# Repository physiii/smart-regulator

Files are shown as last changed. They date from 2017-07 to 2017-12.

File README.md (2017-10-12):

## This repository contains the code, schematic, and layout for a wifi controlled and monitored 5V 3A regulator that works with __open-automation__.

### open-automation is made from a cohesive set of web languages. NodeJS for general processing, socket.io for bidirectional communication. NodeJS is used for generating, setting, and retreiving model (mongodb) data. Websockets is used for transport on microcontrollers. Live token based streaming with JSMPEG decoding on camera devices. Web interface is angularjs. Android app for location beacons. Now supports streaming from behind routers, this is done through websockets; so no port forwarding necessary!

### Can be used for controlling cameras, dead bolts, garage openers, lights, thermostats, media, glass break, and a customizable alert system.

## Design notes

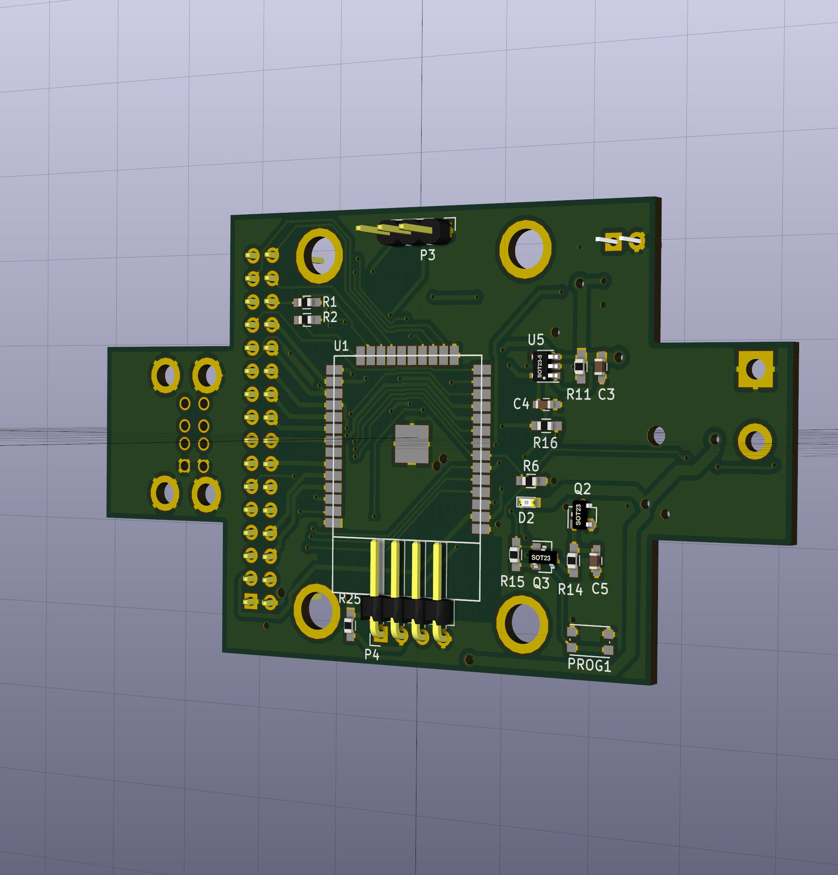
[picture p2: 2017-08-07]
images/5v-smart-solar-regulator-bottom.jpg

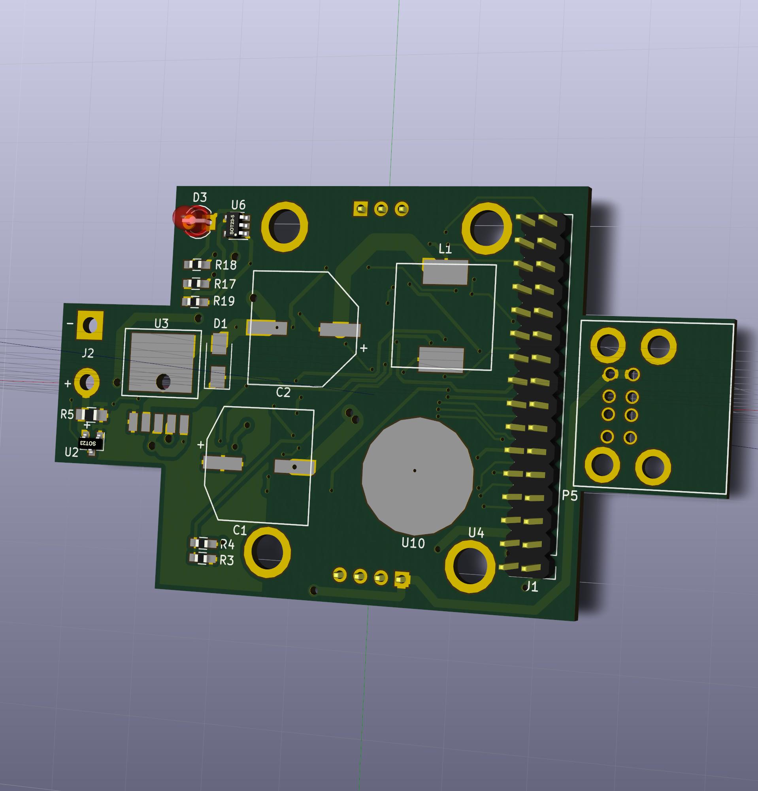
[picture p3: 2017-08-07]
images/5v-smart-solar-regulator-top.jpg

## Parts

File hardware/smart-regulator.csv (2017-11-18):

Reference | Quantity | Value | Footprint | Datasheet | Part Number
BATTERY1 PANEL1 | 2 | CONN_01X02 | open-automation:XT60 | https://www.digikey.com/product-detail/en/phoenix-contact/1934861/277-1607-ND/568644
C1 | 1 | 100uF | Capacitors_THT:CP_Radial_D10.0mm_P3.50mm | https://www.digikey.com/product-detail/en/nichicon/UVR1H101MPD/493-1107-ND/588848 | UVR1H101MPD
C2 | 1 | 1000uF | Capacitors_THT:CP_Radial_D10.0mm_P3.50mm | https://www.digikey.com/product-detail/en/nichicon/UVR0J102MPD1TD/493-12738-1-ND/4328447 | UVR0J102MPD1TD
C3 | 1 | 4.7uF | Capacitors_SMD:C_0603_HandSoldering | https://www.digikey.com/product-detail/en/samsung-electro-mechanics-america-inc/CL10B475KQ8NQNC/1276-2087-1-ND/3890173 | CL10B475KQ8NQNC
C4 | 1 | C_10uF | Capacitors_SMD:C_0603_HandSoldering | https://www.digikey.com/product-detail/en/murata-electronics-north-america/GRM188R61A106ME69D/490-10475-1-ND/5026393 | GRM188R61A106ME69D
C6 | 1 | C_1uF | Capacitors_SMD:C_0603_HandSoldering | https://www.digikey.com/product-detail/en/yageo/CC0603ZRY5V7BB105/311-1372-1-ND/2103156 | CC0603ZRY5V7BB105
C8 C9 C10 | 3 | C_0.1uF | Capacitors_SMD:C_0603_HandSoldering | https://www.digikey.com/product-detail/en/kemet/C0603C104K5RACTU/399-5089-1-ND/1465623 | C0603C104K5RACTU
D1 | 1 | D_Schottky | Diodes_SMD:D_SMA | http://www.digikey.com/scripts/DkSearch/dksus.dll?Detail&itemSeq=233263850&uq=636356340886764109 | B330A-13-F
D2 D3 D4 D5 | 4 | LED | LEDs:LED_0603_HandSoldering | http://www.osram-os.com/Graphics/XPic9/00128792_0.pdf | 475-2512-2-ND
FACTORY1 REBOOT1 PROG1 | 3 | SW_PUSH | Buttons_Switches_SMD:SW_SPST_KMR2 | http://www.mouser.com/ds/2/60/KMR2_9aug12-25127.pdf | KMR211NG LFS
J1 | 1 | Conn_02x05_Odd_Even | Pin_Headers:Pin_Header_Straight_2x05_Pitch2.54mm
L1 | 1 | 47uH | open-automation:L-RAD-7.4mm | https://www.digikey.com/product-detail/en/abracon-llc/AIUR-06-470K/535-13031-ND/2343602 | AIUR-06-470K
P5 | 1 | USB_A_2 | open-automation:USB_A_2 | https://www.digikey.com/product-detail/en/cnc-tech/1002-004-01010/1175-1018-ND/3064749 | 1002-004-01010
Q1 | 1 | Q_NMOS_GSD_AOD4184A | TO_SOT_Packages_SMD:TO-252-2_Rectifier | https://www.digikey.com/products/en?keywords=785-1221-1-ND | AOD4184A
R1 | 1 | R_10m | Resistors_SMD:R_2512_HandSoldering | https://www.digikey.com/product-detail/en/bourns-inc/CRA2512-FZ-R010ELF/CRA2512-FZ-R010ELFCT-ND/1775054 | CRA2512-FZ-R010ELF
R2 R3 R4 R6 R8 R9 R10 R11 | 8 | R_10k | Resistors_SMD:R_0603_HandSoldering | https://www.digikey.com/product-detail/en/yageo/RC0603JR-0710KL/311-10KGRCT-ND/729647 | RC0603JR-0710KL
R7 | 1 | 1K | Resistors_SMD:R_0603_HandSoldering | https://www.digikey.com/product-detail/en/yageo/RC0603JR-071KL/311-1.0KGRTR-ND/726677 | RC0603JR-071KL
U1 | 1 | ESP-WROOM-32 | open-automation:ESP-WROOM-32 | https://www.espressif.com/sites/default/files/documentation/esp_wroom_32_datasheet_en.pdf
U10 | 1 | touchpad | open-automation:touch-pad
U11 | 1 | NCP1117LPST33T3G | TO_SOT_Packages_SMD:SOT-223 | https://www.digikey.com/product-detail/en/on-semiconductor/NCP1117LPST33T3G/NCP1117LPST33T3GOSCT-ND/3462387 | NCP1117LPST33T3G
U2 | 1 | TSL45315CL | open-automation:LIGHT-SENSOR-TSL45315CL | https://www.digikey.com/product-detail/en/ams/TSL45315CL/TSL45315-CLCT-ND/3095326 | TSL45315CL
U3 | 1 | LM2576 | open-automation:Regulator-LM2576 | https://www.digikey.com/product-detail/en/texas-instruments/LM2576SX-5.0-NOPB/LM2576SX-5.0-NOPBCT-ND/3440106 | LM2576SX-5.0/NOPB
U4 | 1 | housing-mounts | open-automation:enclosure-25x38 | https://www.mcmaster.com/#catalog/123/904/=18nyvt2
U5 | 1 | Power-Monitor-INA219 | TO_SOT_Packages_SMD:SOT-23-8_Handsoldering | https://www.digikey.com/product-detail/en/texas-instruments/INA219AIDCNR/296-23770-1-ND/1952550 | INA219AIDCNR
U6 | 1 | SI7020-A20 | open-automation:SI7020-A20 | https://www.digikey.com/product-detail/en/silicon-labs/SI7020-A20-GM1R/336-3596-1-ND/5823452 | SI7020-A20-GM1R

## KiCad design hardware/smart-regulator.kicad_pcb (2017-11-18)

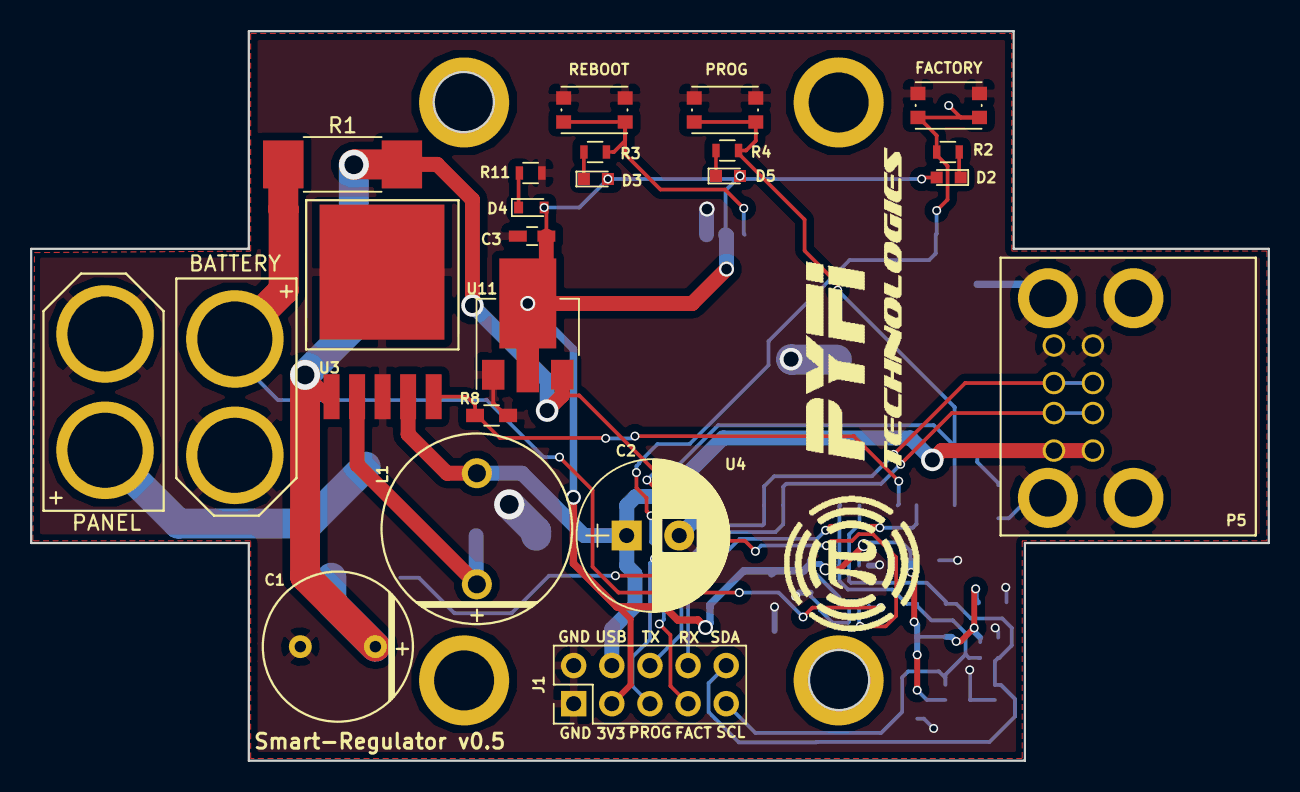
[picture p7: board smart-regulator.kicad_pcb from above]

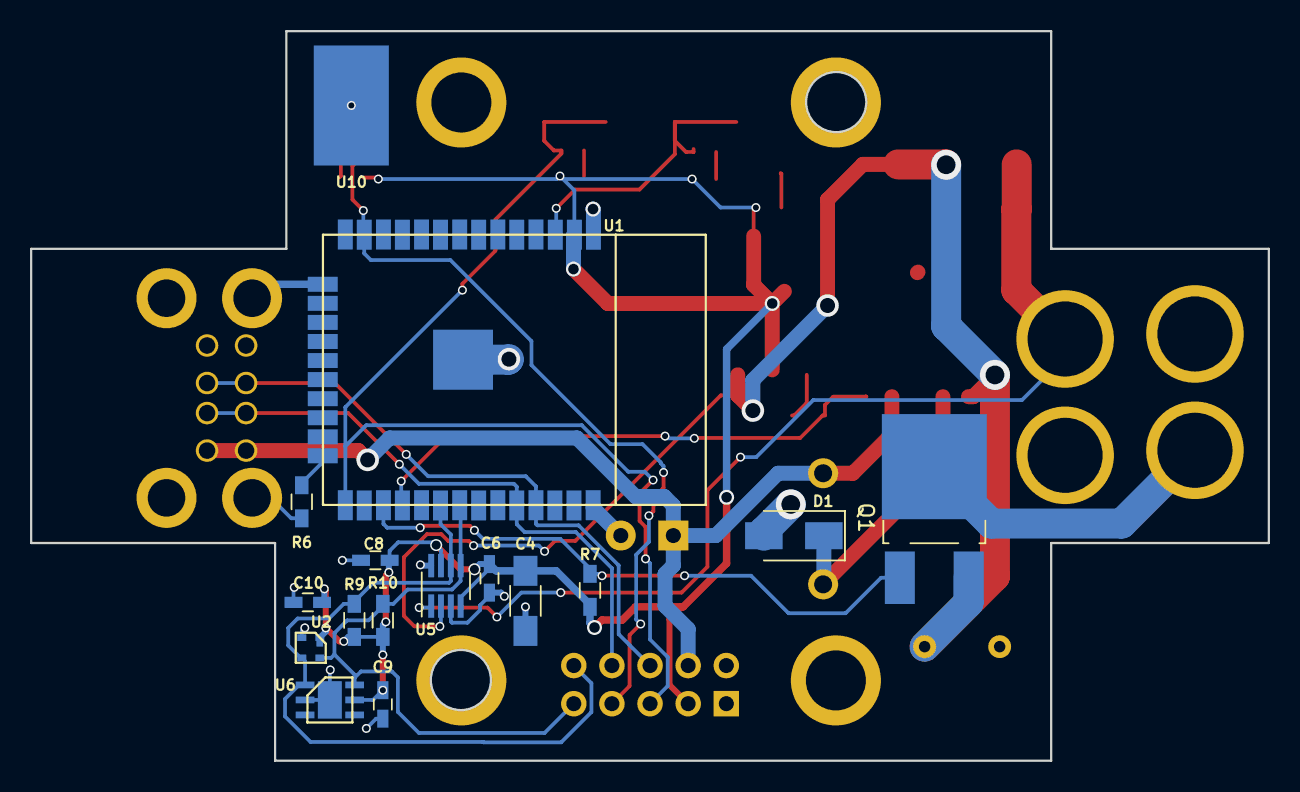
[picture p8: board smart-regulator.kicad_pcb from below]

Board: 2 copper layers, 82.5 x 48.6 mm, 41 parts (16 on the bottom side), 21 nets.

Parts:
BATTERY: CONN_01X02; XT60
C1: 100uF; CAP-RAD-5mm-UVR1H102MHD
C2: 1000uF; CP_Radial_D10.0mm_P3.50mm
C3: 4.7uF; C_0603_HandSoldering
C4: C_10uF; C_1206_HandSoldering
C6: C_1uF; C_0603_HandSoldering
C8, C9, C10: C_0.1uF; C_0603_HandSoldering
D1: D_Schottky; D_SMA
D2, D3, D5: LED; LED_0603
D4: LED; D_0603
FACTORY: SW_PUSH; SW_SPST_KMR2
J1: Conn_02x05_Odd_Even; Pin_Header_Straight_2x05_Pitch2.54mm
L1: 47uH; L-RAD-7.4mm
LOGO: LOGO
P5: USB_A_2
PANEL: CONN_01X02; XT60
PROG: SW_PUSH; SW_SPST_KMR2
Q1: Q_NMOS_GSD_AOD4184A; TO-252-2_Rectifier
R1: R_10m; R_2512_HandSoldering
R2, R3, R4, R11: R_10k; R_0603
R6, R8, R9, R10: R_10k; R_0603_HandSoldering
R7: 1K; R_0603_HandSoldering
REBOOT: SW_PUSH; SW_SPST_KMR2
U1: ESP-WROOM-32
U2: TSL45315CL; LIGHT-SENSOR-TSL45315CL
U3: LM2576; Regulator-LM2576
U4: housing-mounts; enclosure-25x38
U5: Power-Monitor-INA219; SOT-23-8_Handsoldering
U6: SI7020-A20
U10: touchpad; touch-pad
U11: NCP1117LPST33T3G; SPX1117M3

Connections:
3V3: C3.1, C4.1, C6.1, C8.2, C9.1, C10.1, D2.2, D3.2, D4.2, D5.2, J1.3, R7.1, R9.2, R10.2, U1.2, U2.1, U5.4, U5.7, U6.5, U11.2
BATTERY: BATTERY.1, R1.1, U5.1
EN: R3.2, REBOOT.1, U1.3
FACTORY: FACTORY.1, J1.7, R2.2, U1.13, U10.1
GND: BATTERY.2, C1.2, C2.2, C3.2, C4.2, C6.2, C8.1, C9.2, C10.2, D1.2, FACTORY.2, J1.1, J1.2, P5.1, P5.7, PANEL.2, PROG.2, R6.1, R8.2, R11.2, REBOOT.2, U1.1, U2.2, U3.3, U5.3, U5.8, U6.2, U11.1
IO2: R6.2, U1.24
unnamed: D1.1, L1.1, U3.2
unnamed: D2.1, R2.1
unnamed: D3.1, R3.1
unnamed: D4.1, R11.1
unnamed: D5.1, R4.1
PANEL_SW: Q1.1, R7.2, U1.27
POWER_EN: R8.1, U1.28, U3.5
PROG: J1.5, PROG.1, R4.2, U1.25
RXD: J1.8, P5.4, P5.6, U1.34
SCL: J1.9, R10.1, U1.31, U2.4, U5.5, U6.6
SDA: J1.10, R9.1, U1.30, U2.3, U5.6, U6.1
TXD: J1.6, P5.3, P5.5, U1.35
V_MAIN: C1.1, Q1.3, R1.2, U3.1, U5.2, U11.3
V_PANEL: PANEL.1, Q1.2
V_USB: C2.1, J1.4, L1.2, P5.2, U3.4

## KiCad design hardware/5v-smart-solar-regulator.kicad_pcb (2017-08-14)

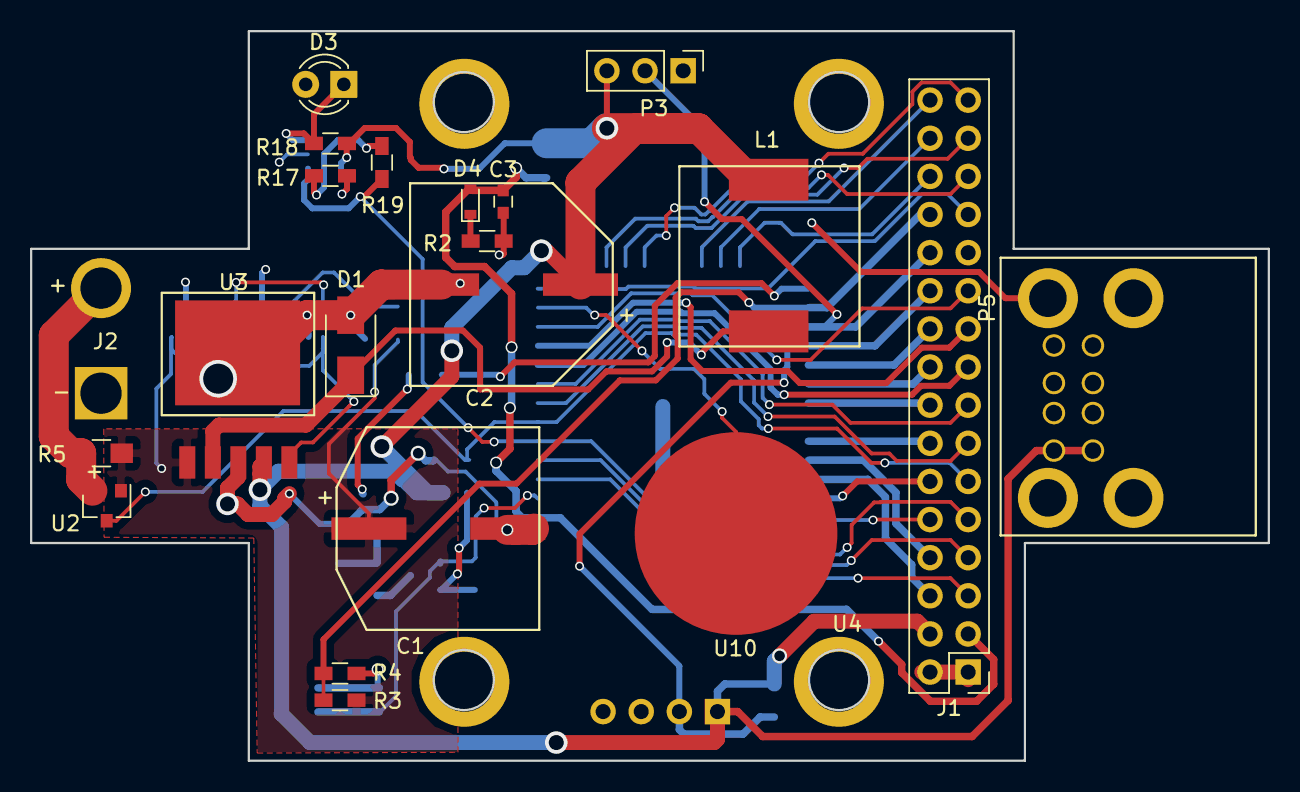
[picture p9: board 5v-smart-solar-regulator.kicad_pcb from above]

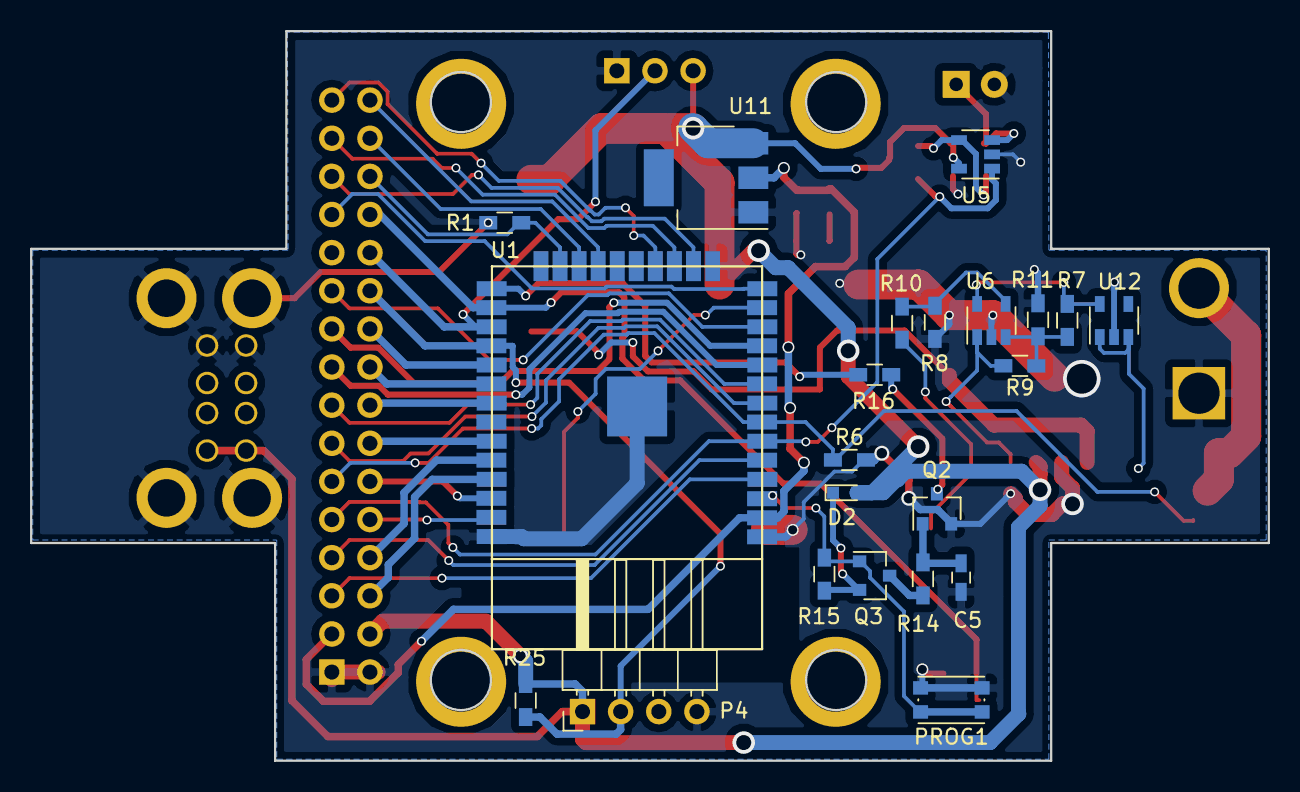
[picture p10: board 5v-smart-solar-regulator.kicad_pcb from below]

Board: 2 copper layers, 82.5 x 48.6 mm, 44 parts (22 on the bottom side), 47 nets.

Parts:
C1: 100uF; smd-cap-13.5
C2: 1000uF; smd-cap-13.5
C3: 4.7uF; C_0603
C5: 4.7uF; C_0603_HandSoldering
D1: D_Schottky; D_SMA
D2: LED; LED_0603
D3: LED; LED_D3.0mm
D4: LED; D_0603
J1: CONN_02X16; Pin_Header_Straight_2x16_Pitch2.54mm
J2: CONN_01X02; battery_input
L1: 47uH; Inductor-SRR1210
P3: CONN_01X03; PIR-SR501
P4: CONN_01X04; Pin_Header_Angled_1x04_Pitch2.54mm
P5: USB_A_2
PROG1: SW_PUSH; SW_SPST_KMR2
Q2: Q_NMOS_GSD; SOT-23
Q3: Q_PMOS_GSD; SOT-23
R1, R25: 10K; R_0603_HandSoldering
R2, R14, R15, R16: 1K; R_0603_HandSoldering
R3, R10: 100K; R_0603_HandSoldering
R4: 25K; R_0603_HandSoldering
R5: 50m; R_0805_HandSoldering
R6: 5K; R_0603_HandSoldering
R7, R11: 82K; R_0603_HandSoldering
R8: 30K; R_0603_HandSoldering
R9: 3M; R_0603_HandSoldering
R17: 22K; R_0603_HandSoldering
R18: 1M; R_0603_HandSoldering
R19: 180K; R_0603_HandSoldering
U1: ESP-WROOM-32
U2: ZXCT1107; Current_sense-ZXCT1107
U3: LM2576; Regulator-LM2576
U4: housing-mounts; enclosure-25x38
U5, U6: OPA344NA/3K; SOT-23-5
U10: touchpad; touch-pad
U11: SPX1117M3-L-3-3/TR; SOT-223
U12: AP2204K-5.0TRG1; SOT-23-5

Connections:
3v3: C3.1, D4.2, J1.3, U1.2, U11.2
5V: C2.1, D2.2, J1.4, L1.2, P3.3, P4.1, P5.2, R18.2, R25.2, U3.4, U5.5, U11.3
5V_ref: R7.1, U6.5, U12.5
BATTERY: J2.1, R5.1, U2.3
EN: PROG1.1, Q3.1, R15.2, U1.3
GND: C1.2, C2.2, C3.2, C5.1, D1.2, D3.2, J1.1, J1.2, J2.2, P3.1, P4.4, P5.1, P5.7, PROG1.2, Q2.2, R1.2, R2.2, R4.1, R6.1, R8.2, R11.2, R17.2, U1.1, U3.3, U5.2, U6.2, U11.1, U12.2
IO0: R16.1, U1.25
IO4: J1.26, R3.2, R4.2, U1.26
IO5: J1.20, U1.29
IO12: J1.25, U1.14
IO13: J1.27, U1.16
IO14: U1.13, U10.1
IO15: J1.28, R1.1, U1.23
IO16: J1.24, P3.2, U1.27
IO17: J1.22, P4.2, R25.1, U1.28
IO18: J1.18, U1.30
IO19: J1.16, U1.31
IO21: J1.14, U1.33
IO22: J1.12, U1.36
IO23: J1.10, U1.37
IO25: J1.17, U1.10
IO26: J1.19, U1.11
IO27: J1.21, U1.12
IO32: J1.13, U1.8
IO33: J1.15, U1.9
IO34: J1.9, R19.2, U1.6, U5.1
IO35: J1.11, R6.2, U1.7, U2.1
unnamed: C5.2, Q2.1, R14.2
unnamed: D1.1, L1.1, U3.2
unnamed: D2.1, Q3.2, R15.1
unnamed: D3.1, R18.1, U5.3
unnamed: D4.1, R2.1
unnamed: Q2.3, R16.2
unnamed: Q3.3, R14.1
unnamed: R8.1, R10.2, U6.4
unnamed: R7.2, R9.1, R11.1, U6.3
unnamed: R17.1, R19.1, U5.4
RXD: J1.8, U1.34
SD0: J1.32, U1.21
SD1: J1.30, U1.22
SD2: J1.29, U1.17
SD3: J1.31, U1.18
SENSOR_VN: J1.7, U1.5
SENSOR_VP: J1.5, U1.4
TXD: J1.6, U1.35
Vin: C1.1, R3.1, R5.2, R10.1, U2.2, U3.1, U12.1, U12.3
power_EN: R9.2, U3.5, U6.1

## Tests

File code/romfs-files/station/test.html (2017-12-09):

 | Detected Browser: ...
Click Here to have the test server send a big picture by http.
Dumb Increment Demo

Websocket connection not initialized | dumb increment-protocol
The incrementing number is coming from the server at 20Hz and is individual for each connection to the server... try opening a second browser window. The button sends a message over the websocket link to ask the server to zero just this connection's number.

Mirror Demo

Websocket connection not initialized | lws-mirror-protocol
Use the mouse to draw on the canvas below -- all other browser windows open on this page see your drawing in realtime and you can see any of theirs as well. The lws-mirror protocol doesn't interpret what is being sent to it, it just re-sends it to every other websocket it has a connection with using that protocol, including the guy who sent the packet. libwebsockets-test-client joins in by spamming circles on to this shared canvas when run.
Drawing color:

Close Testing

Websocket connection not initialized | Open and close testing
To help with open and close testing, you can open and close a connection by hand using the buttons. "Close" closes the connection from the browser with code 3000 and reason 'Bye!". "Request Server Close" sends a message asking the server to initiate the close, which it does with code 1001 and reason "Seeya".

Server info

Websocket connection not initialized | Server Info
This information is sent by the server over a ws[s] link and updated live whenever the information changes server-side.

POST

POST Form testing
This tests POST handling in lws.
FORM 1: send with urlencoded POST body args Some text:
FORM 2: send with multipart/form-data (can handle file upload, test limited to 100KB) Some text:

Looking for support? https://libwebsockets.org, https://github.com/warmcat/libwebsockets
Join the mailing list: https://libwebsockets.org/mailman/listinfo/libwebsockets
Reset to configuration mode
3.9MB Copy of War and Peace served using a 1.2MB gzip directly from inside a zip file

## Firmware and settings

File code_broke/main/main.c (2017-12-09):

/*
 * Copyright (C) 2017 Andy Payne <physiphile@gmail.com>
 *
 * This file is made available under the Creative Commons CC0 1.0
 * Universal Public Domain Dedication.
 *
 * The person who associated a work with this deed has dedicated
 * the work to the public domain by waiving all of his or her rights
 * to the work worldwide under copyright law, including all related
 * and neighboring rights, to the extent allowed by law. You can copy,
 * modify, distribute and perform the work, even for commercial purposes,
 * all without asking permission.
 *
 * The test apps are intended to be adapted for use in your code, which
 * may be proprietary.	So unlike the library itself, they are licensed
 * Public Domain.
 *
 */
#include <libwebsockets.h>
#include <nvs_flash.h>
bool initiate_protocols = false;
bool token_connected = false;
bool token_received = false;

#include "plugins/protocol_token.c"
#include "plugins/protocol_buttons.c"
#include "plugins/protocol_power.c"
#include "plugins/protocol_climate.c"

//#include "plugins/protocol_update.c"
//#include "plugins/protocol_LED.c"
//#include "plugins/protocol_speaker.c"
//#include "plugins/protocol_motion.c"
//#include "plugins/protocol_audio.c"
//#include "plugins/protocol_ota.c"

#include "plugins/protocol_esp32_lws_ota.c"
#include "../components/libwebsockets/plugins/protocol_lws_meta.c"
#include <protocol_esp32_lws_reboot_to_factory.c>

/*#define DATA_LENGTH          512
#define RW_TEST_LENGTH       127  
#define POWER_DELAY_TIME    5000 

#define I2C_EXAMPLE_MASTER_SCL_IO    19
#define I2C_EXAMPLE_MASTER_SDA_IO    18
#define I2C_EXAMPLE_MASTER_NUM I2C_NUM_1
#define I2C_EXAMPLE_MASTER_TX_BUF_DISABLE   0
#define I2C_EXAMPLE_MASTER_RX_BUF_DISABLE   0
#define I2C_EXAMPLE_MASTER_FREQ_HZ   100000

#define WRITE_BIT  I2C_MASTER_WRITE
#define READ_BIT   I2C_MASTER_READ
#define ACK_CHECK_EN   0x1
#define ACK_CHECK_DIS  0x0
#define ACK_VAL    0x0
#define NACK_VAL   0x1*/

static const struct lws_protocols protocols_station[] = {
	{
		"http-only",
		lws_callback_http_dummy,
		0,
		1024, 0, NULL, 900
	},
	LWS_PLUGIN_PROTOCOL_TOKEN,
	LWS_PLUGIN_PROTOCOL_BUTTONS,
	LWS_PLUGIN_PROTOCOL_POWER,
	LWS_PLUGIN_PROTOCOL_CLIMATE,
	//LWS_PLUGIN_PROTOCOL_LED,
	//LWS_PLUGIN_PROTOCOL_SPEAKER,
	//LWS_PLUGIN_PROTOCOL_MOTION,
	//LWS_PLUGIN_PROTOCOL_AUDIO,
	//LWS_PLUGIN_PROTOCOL_OTA,
	//LWS_PLUGIN_PROTOCOL_ESPLWS_SCAN,
	LWS_PLUGIN_PROTOCOL_ESPLWS_RTF,	// helper protocol to allow reset to factory
	{ NULL, NULL, 0, 0, 0, NULL, 0 } /* terminator */
};

static const struct lws_protocol_vhost_options pvo_headers = {
        NULL,
        NULL,
        "Keep-Alive:",
        "timeout=5, max=20",
};

/* reset to factory mount */
static const struct lws_http_mount mount_station_rtf = {
	.mountpoint		= "/esp32-rtf",
	.origin			= "esplws-rtf",
	.origin_protocol	= LWSMPRO_CALLBACK,
	.mountpoint_len		= 10,
};

/*
 * this makes a special URL "/formtest" which gets passed to
 * the "protocol-post-demo" plugin protocol for handling
 */
static const struct lws_http_mount mount_station_post = {
	.mount_next		= &mount_station_rtf,
	.mountpoint		= "/formtest",
	.origin			= "protocol-post-demo",
	.origin_protocol	= LWSMPRO_CALLBACK,
	.mountpoint_len		= 9,
};

/*
 * this serves "/station/..." in the romfs at "/" in the URL namespace
 */
static const struct lws_http_mount mount_station = {
        .mount_next		= &mount_station_post,
        .mountpoint		= "/",
        .origin			= "/station",
        .def			= "test.html",
        .origin_protocol	= LWSMPRO_FILE,
        .mountpoint_len		= 1,
};

esp_err_t event_handler(void *ctx, system_event_t *event)
{
	// deal with your own user events here first 

	return lws_esp32_event_passthru(ctx, event);
}

/*
 * This is called when the user asks to "Identify physical device"
 * he is configuring, by pressing the Identify button on the AP
 * setup page for the device.
 *
 * It should do something device-specific that
 * makes it easy to identify which physical device is being
 * addressed, like flash an LED on the device on a timer for a
 * few seconds.
 */
void
lws_esp32_identify_physical_device(void)
{
	lwsl_notice("%s\n", __func__);
}

void lws_esp32_leds_timer_cb(TimerHandle_t th)
{
}

static TimerHandle_t flash_timer;
static void flash_timer_cb(TimerHandle_t t)
{
	//flashes++;
	//lwsl_notice("timer....\n");
	//xTimerStop(flash_timer, 0);
	/*if (flashes & 1)
		gpio_output_set(0, 1 << GPIO_ID, 1 << GPIO_ID, 0);
	else
		gpio_output_set(1 << GPIO_ID, 0, 1 << GPIO_ID, 0);*/
}

uint8_t mac[6];
char mac_str[20] = "init";

struct lws_vhost *vh;
static struct lws_context_creation_info info;
static struct lws_client_connect_info i;
struct lws_context *context;
struct lws *wsi_tokens, *wsi_buttons, *wsi_power, *wsi_climate;



void init_protocols(void)
{
	//esp_err_t ESP_OK = esp_wifi_sta_get_ap_info();
	// ------------------ //
	// initiate protocols //
	// ------------------ //
	while (1) 
	{
		if (!token_connected)
		{
			wsi_tokens = NULL;
			//printf("\CONNECTING!\n");
			i.pwsi = &wsi_tokens;
			i.protocol = "token-protocol";
			i.path = "/tokens";
		        wsi_tokens = lws_client_connect_via_info(&i);
		        while (!wsi_tokens) {
			        wsi_tokens = lws_client_connect_via_info(&i);
				taskYIELD();
				vTaskDelay(5000/portTICK_PERIOD_MS);
	       		}
		}

		if (!power_connected && token_connected) {
			wsi_power = NULL;
			i.pwsi = &wsi_power;
			i.protocol = "power-protocol";
			i.path = "/power";
       			wsi_power = lws_client_connect_via_info(&i);
       			while (!wsi_power) {
			        wsi_power = lws_client_connect_via_info(&i);
				taskYIELD();
				vTaskDelay(2000/portTICK_PERIOD_MS);
       			}
			power_connected = true;
		}

		printf("\climate_connected %d  token_connected %d\n",climate_connected,token_connected);
		if (!climate_connected && token_connected) {
			wsi_climate = NULL;
			i.pwsi = &wsi_climate;
			i.protocol = "climate-protocol";
			i.path = "/climate";
			printf("\climate connecting\n");
       			wsi_climate = lws_client_connect_via_info(&i);
		        while (!wsi_climate) {
			        wsi_climate = lws_client_connect_via_info(&i);
				taskYIELD();
				vTaskDelay(2000/portTICK_PERIOD_MS);
		        }
			climate_connected = true;
		}
	

			/*
			if (initiate_protocols && token_connected) {
			wsi_buttons = NULL;
			i.pwsi = &wsi_buttons;
			i.protocol = "buttons-protocol";
			i.path = "/buttons";
       			wsi_buttons = lws_client_connect_via_info(&i);
       			while (!wsi_buttons) {
			        wsi_buttons = lws_client_connect_via_info(&i);
				taskYIELD();
				vTaskDelay(2000/portTICK_PERIOD_MS);
       			}
			vTaskDelay(1000/portTICK_PERIOD_MS);
			i.protocol = "LED-protocol";
			i.path = "/LED";
		        wsi = lws_client_connect_via_info(&i);
		        while (!wsi) {
			        wsi = lws_client_connect_via_info(&i);
			taskYIELD();
				vTaskDelay(1000/portTICK_PERIOD_MS);
		        }
	
			i.protocol = "motion-protocol";
			i.path = "/motion";
		        wsi = lws_client_connect_via_info(&i);
		        while (!wsi) {
			        wsi = lws_client_connect_via_info(&i);
				taskYIELD();
				vTaskDelay(1000/portTICK_PERIOD_MS);
		        }
	
			i.protocol = "audio-protocol";
			i.path = "/audio";
		        wsi = lws_client_connect_via_info(&i);
		        while (!wsi) {
			        wsi = lws_client_connect_via_info(&i);
				taskYIELD();
				vTaskDelay(1000/portTICK_PERIOD_MS);
		        }

			i.protocol = "ota-protocol";
			i.path = "/update";
		        wsi = lws_client_connect_via_info(&i);
		        while (!wsi) {
			        wsi = lws_client_connect_via_info(&i);
				taskYIELD();
				vTaskDelay(1000/portTICK_PERIOD_MS);
		        }

			i.protocol = "esplws-scan";
		        wsi = lws_client_connect_via_info(&i);
		        while (!wsi) {
		        wsi = lws_client_connect_via_info(&i);
			taskYIELD();
				vTaskDelay(1000/portTICK_PERIOD_MS);
		        }*/
			



			/*while (!lws_service(context, 3000)) {
				taskYIELD();
			}*/
		
		// ----------------- //
		// service protocols //
		// ----------------- //
		lws_service(context, 10 * 1000);
		taskYIELD();
		vTaskDelay(1000/portTICK_PERIOD_MS);
	}
}



void app_main(void)
{
	nvs_flash_init();
	lws_esp32_wlan_config();
	ESP_ERROR_CHECK( esp_event_loop_init(event_handler, NULL));
	lws_esp32_wlan_start_station();

	memset(&info, 0, sizeof(info));
	info.port = CONTEXT_PORT_NO_LISTEN;
	info.protocols = protocols_station;
	info.gid = -1;
	info.uid = -1;
	info.ws_ping_pong_interval = 10;
	context = lws_esp32_init(&info, &vh);

	memset(&i, 0, sizeof i);
	//i.address = "192.168.0.10";
	i.address = "192.168.0.10";
        i.port = 4000;
	i.ssl_connection = 0;
	i.host = i.address;
	i.origin = i.host;
        i.ietf_version_or_minus_one = -1;
	i.context = context;

	init_protocols();
	printf("EXITED?!\n");
        return 0;
}
